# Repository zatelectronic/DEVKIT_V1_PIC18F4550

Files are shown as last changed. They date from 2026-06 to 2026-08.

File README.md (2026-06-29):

<div align="center">

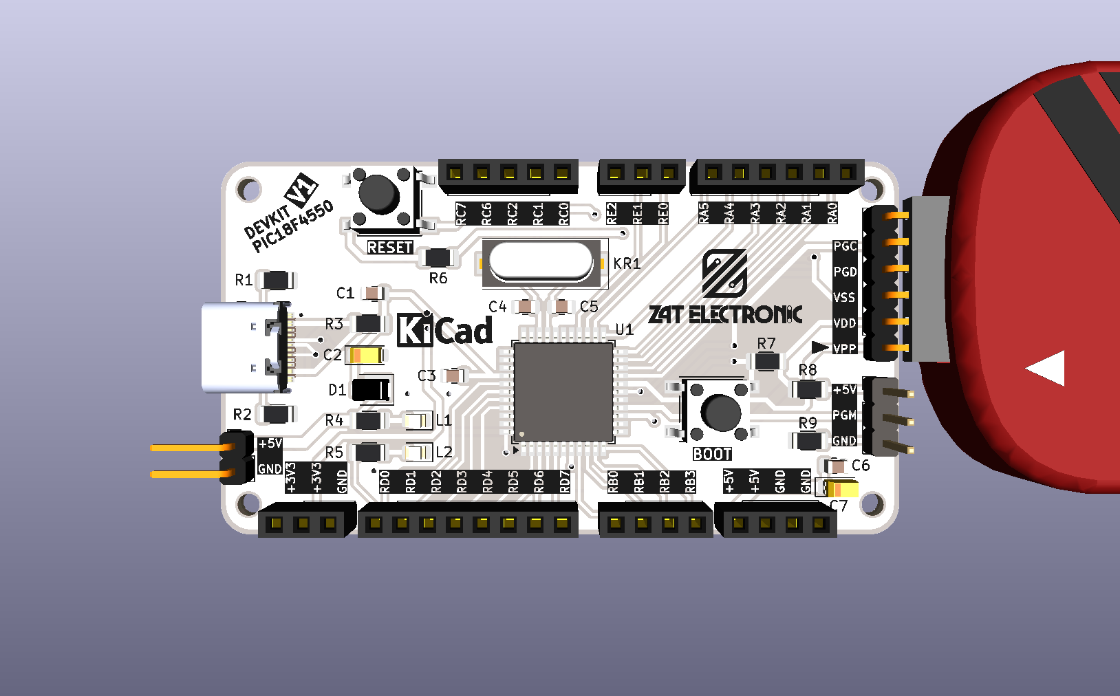
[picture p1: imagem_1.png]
DEVKIT V1 PIC18F4550 — Vista Superior


# DEVKIT V1 PIC18F4550

**Kit de desenvolvimento profissional para o microcontrolador PIC18F4550 com USB nativo, programação via conector ICSP compatível com programador externo, reguladores 5V e 3,3V, oscilador SMD, botões RESET e BOOT, 2 LEDs de status e exposição completa de todos os ports GPIO**










</div>

---

## 📋 Índice

- [DEVKIT V1 PIC18F4550](#devkit-v1-pic18f4550)
  - [📋 Índice](#-índice)
  - [Visão Geral](#visão-geral)
  - [Renders 3D](#renders-3d)
  - [Arquitetura do Projeto](#arquitetura-do-projeto)
  - [Funcionalidades](#funcionalidades)
  - [Especificações Técnicas](#especificações-técnicas)
  - [Arquitetura de Alimentação](#arquitetura-de-alimentação)
  - [Interface USB Nativa](#interface-usb-nativa)
  - [Conector ICSP — Programação](#conector-icsp--programação)
    - [J5 — ICSP Principal (6 pinos angulado)](#j5--icsp-principal-6-pinos-angulado)
    - [J6 — Conector Auxiliar (3 pinos)](#j6--conector-auxiliar-3-pinos)
  - [Mapa Completo de Conectores e GPIO](#mapa-completo-de-conectores-e-gpio)
    - [J1 — Alimentação Externa (2 pinos)](#j1--alimentação-externa-2-pinos)
    - [J2 — Port RA (5 pinos)](#j2--port-ra-5-pinos)
    - [J3 — Port RC Superior (3 pinos)](#j3--port-rc-superior-3-pinos)
    - [J4 — Port RC Inferior (6 pinos)](#j4--port-rc-inferior-6-pinos)
    - [J7 — Port RE (4 pinos)](#j7--port-re-4-pinos)
    - [J8 — Port RB (4 pinos)](#j8--port-rb-4-pinos)
    - [J9 — Port RD (8 pinos)](#j9--port-rd-8-pinos)
    - [J10 — Alimentações (3 pinos)](#j10--alimentações-3-pinos)
  - [Lista de Materiais](#lista-de-materiais)
    - [Microcontrolador](#microcontrolador)
    - [USB Type-C e Alimentação](#usb-type-c-e-alimentação)
    - [Programador ICSP](#programador-icsp)
    - [Conectores GPIO](#conectores-gpio)
  - [Estrutura do Repositório](#estrutura-do-repositório)
  - [Como Usar](#como-usar)
    - [1. Gravando firmware via ICSP](#1-gravando-firmware-via-icsp)
    - [2. Alimentação](#2-alimentação)
    - [3. Modo Bootloader USB (BOOT)](#3-modo-bootloader-usb-boot)
    - [Exemplo de código — MPLAB XC8](#exemplo-de-código--mplab-xc8)
    - [Ferramentas recomendadas](#ferramentas-recomendadas)
  - [Sobre](#sobre)

---

## Visão Geral

**DEVKIT V1 PIC18F4550** é um kit de desenvolvimento completo para o microcontrolador **PIC18F4550-IPT** (TQFP-44 SMD), projetado pela **ZAT ELECTRONIC** utilizando **KiCad 10** com esquemático hierárquico dividido em quatro sub-folhas: **Microcontrolador**, **USB Type-C**, **Programador ICSP** e **Conexões GPIO**.

O PIC18F4550 é um microcontrolador de 8 bits da família PIC18 com **USB 2.0 Full Speed nativo** (RC4/D− e RC5/D+), memória Flash de 32KB, SRAM de 2KB e EEPROM de 256 bytes. O DEVKIT expõe todos os ports GPIO (RA, RB, RC, RD, RE) em conectores fêmea de 2,54mm, inclui reguladores de tensão **5V** e **3,3V** on-board, oscilador a cristal SMD de **8MHz**, botões **RESET** e **BOOT** tácteis SMD, **2 LEDs SMD** de status e conector **ICSP de 6 pinos** angulado compatível com programador externo.

> 💡 O modelo 3D do programador externo (`Microchip - PICkit3.stp`) está incluído no projeto — as imagens 3D mostram o DEVKIT conectado a um programador externo, evidenciando a integração direta pelo conector ICSP lateral.

---

## Renders 3D

<div align="center">

Vista Superior com programador externo

*Vista superior — PIC18F4550 TQFP-44, USB-C, cristal SMD, botões RESET/BOOT e conectores GPIO*

<br/>

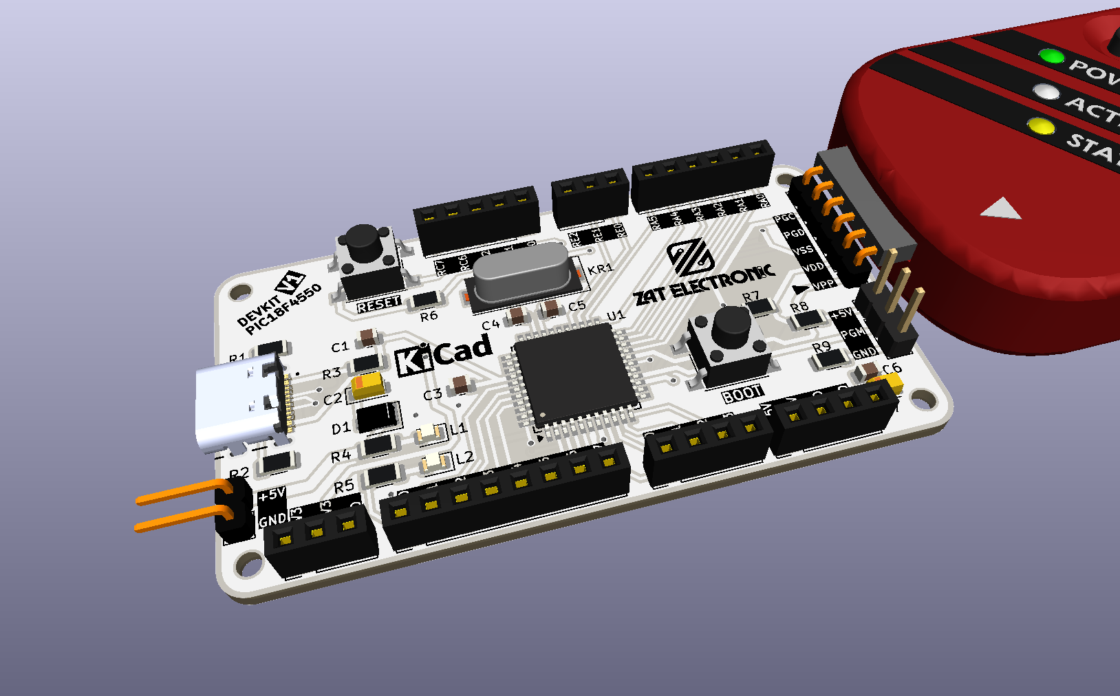
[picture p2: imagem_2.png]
Vista Isométrica com programador externo


*Vista isométrica — DEVKIT conectado ao programador externo pelo conector ICSP de 6 pinos*

<br/>

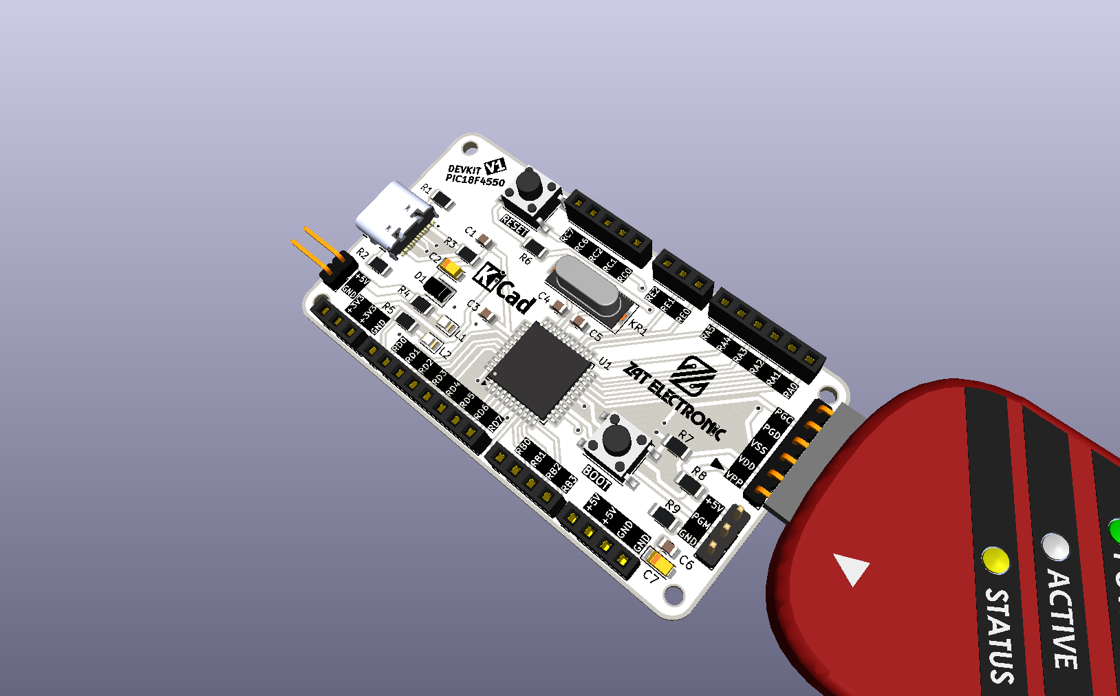
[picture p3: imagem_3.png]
Vista inferior isométrica


*Vista inferior isométrica — exposição completa dos ports RD (8 pinos) e RB (4 pinos) na borda inferior*

<br/>

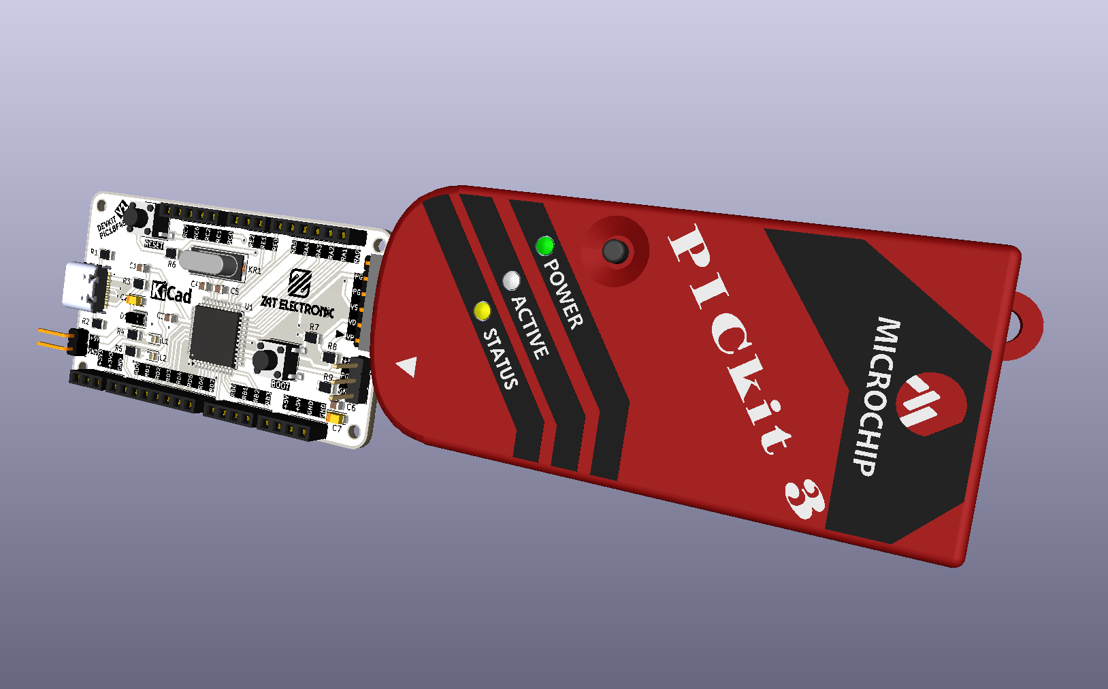
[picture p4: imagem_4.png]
Vista completa com programador


*Visão completa do ecossistema — DEVKIT + programador externo para gravação de firmware*

</div>

---

## Arquitetura do Projeto

O projeto é organizado em **esquemático hierárquico** com 4 sub-folhas independentes:

```
DEVKIT_V1_PIC18F4550.kicad_sch  (folha raiz)
│
├── MICROCONTROLADOR.kicad_sch
│   ├── PIC18F4550-IPT (TQFP-44)
│   ├── Cristal 8MHz HC-49/SD SMD (KR1)
│   ├── Capacitores de cristal 22pF (C3, C4)
│   ├── Capacitor de desacoplamento USB 470nF (C5)
│   ├── Botão RESET táctil SMD (TACTIL_SWITCH1)
│   ├── Botão BOOT táctil SMD (TACTIL_SWITCH2)
│   ├── LEDs SMD 0805 — L1, L2
│   └── Resistores pull-up/proteção — R5, R6, R7
│
├── TYPE-C_USB.kicad_sch
│   ├── Conector USB-C (USB4105GFA SMD)
│   ├── Regulador 3,3V AMS1117-3.3 (U2 — SOT-223)
│   ├── Diodo Schottky SS1P3L (D1 — DO-220AA)
│   ├── Capacitores eletrolíticos 10µF/16V (C2, C8)
│   ├── Capacitores de desacoplamento 100nF (C1, C6)
│   ├── Resistores CC 5,1KΩ (R3, R4 — para USB-C)
│   ├── Resistores 1KΩ e 0Ω (R1, R2)
│   └── LED SMD (L1 — status alimentação)
│
├── PROGRAMADOR.kicad_sch
│   ├── Conector ICSP 6 pinos angulado (J5)
│   ├── Conector auxiliar de programação (J6)
│   └── Resistores pull-up 10KΩ (R8, R9)
│
└── CONEXÕES.kicad_sch
    ├── J1  — Conector alimentação +5V/GND (2 pinos)
    ├── J2  — Port RA (5 pinos: RA0–RA5)
    ├── J3  — Port RC superior (3 pinos: RC0–RC2)
    ├── J4  — Port RC inferior (6 pinos: RC6, RC7)
    ├── J7  — Port RE (4 pinos: RE0–RE2)
    ├── J8  — Port RB (4 pinos: RB0–RB3)
    ├── J9  — Port RD (8 pinos: RD0–RD7)
    └── J10 — Alimentações (3 pinos: +5V / +3,3V / GND)
```

---

## Funcionalidades

- ✅ **PIC18F4550-IPT** (TQFP-44 SMD) — MCU 8 bits, 32KB Flash, 2KB SRAM, 256B EEPROM
- ✅ **USB 2.0 Full Speed nativo** — RC4/D− e RC5/D+ conectados ao conector USB-C
- ✅ **Conector USB-C** (USB4105GFA SMD) — entrada moderna com resistores CC 5,1KΩ
- ✅ **Regulador 3,3V** (AMS1117-3.3 SOT-223) — saída 3,3V para periféricos de baixa tensão
- ✅ **Alimentação 5V** via USB-C ou conector externo J1
- ✅ **Cristal 8MHz SMD** (HC-49/SD) — oscilador externo de alta estabilidade
- ✅ **Botão RESET** (TACTIL_SWITCH1 — SMD 6×6×6mm) — reset do microcontrolador
- ✅ **Botão BOOT** (TACTIL_SWITCH2 — SMD 6×6×6mm) — entrada em modo bootloader USB
- ✅ **2 LEDs SMD 0805** (L1, L2) — indicadores de status programáveis
- ✅ **Conector ICSP J5** — 6 pinos angulado para programador externo (PGC, PGD, MCLR, VDD, VSS, VPP)
- ✅ **Conector auxiliar J6** — 3 pinos (+5V / PGM / GND) para programação low-voltage
- ✅ **Diodo Schottky SS1P3L** (DO-220AA) — proteção na linha VBUS
- ✅ **Todos os ports GPIO expostos** — RA, RB, RC, RD, RE em conectores fêmea 2,54mm
- ✅ **Capacitores de desacoplamento** distribuídos — C3, C4, C5, C6 (0805 SMD)
- ✅ **Capacitores eletrolíticos** C2, C7, C8 (EIA-3216 SMD) — filtragem de alimentação
- ✅ **4 furos de fixação** — montagem em painéis e caixas
- ✅ **Esquemático hierárquico** em 4 sub-folhas — organização profissional do projeto

---

## Especificações Técnicas

| Parâmetro | Valor |
|---|---|
| **Microcontrolador** | PIC18F4550-IPT |
| **Encapsulamento MCU** | TQFP-44 (10×10mm, passo 0,8mm) |
| **Arquitetura** | 8 bits — PIC18 |
| **Memória Flash** | 32 KB |
| **SRAM** | 2 KB |
| **EEPROM** | 256 bytes |
| **USB** | Full Speed 2.0 nativo (12 Mbps) |
| **Clock** | 8 MHz (cristal externo HC-49/SD SMD) |
| **Tensão de operação** | 2,0V – 5,5V |
| **Tensão da placa** | 5V (USB-C ou J1) |
| **Regulador 3,3V** | AMS1117-3.3 (SOT-223) |
| **Conector USB** | USB-C — USB4105GFA SMD |
| **Conector ICSP** | 6 pinos angulado (PGC/PGD/MCLR/VDD/VSS/VPP) |
| **GPIO exposto** | RA (5), RB (4), RC (7), RD (8), RE (3) = 27 pinos |
| **Botões** | RESET + BOOT (SMD táctil 6×6×6mm) |
| **LEDs** | 2x SMD 0805 |
| **Resistores** | SMD 1206 |
| **Capacitores** | SMD 0805 + EIA-3216 |
| **Ferramenta de Projeto** | KiCad 10 — esquemático hierárquico |
| **Tipo de montagem** | SMD |

---

## Arquitetura de Alimentação

```
USB-C (VBUS 5V)
      │
  [SS1P3L D1]  ← Proteção Schottky
      │
     5V ──────────────────────────────────► J1 (+5V)
      │                                     J10 (+5V)
      │                                     VDD do PIC18F4550
      │
  [AMS1117-3.3 U2]
      │
    3,3V ────────────────────────────────► J10 (+3,3V)
                                           Periféricos 3,3V

Alimentação alternativa:
J1 (+5V / GND) ──► entrada direta de fonte externa 5V
```

---

## Interface USB Nativa

O PIC18F4550 possui **USB 2.0 Full Speed integrado** no próprio chip, sem necessidade de conversor externo:

```
USB-C (USB4105GFA)
    │
    ├── D− (CC1/CC2 com 5,1KΩ) ──► RC4/D− do PIC18F4550
    └── D+ (CC1/CC2 com 5,1KΩ) ──► RC5/D+ do PIC18F4550

R3, R4 (5,1KΩ) — resistores CC para identificação USB-C
C5 (470nF)     — capacitor de desacoplamento USB do PIC
```

> 💡 Para utilizar o USB, o firmware deve implementar a pilha USB do PIC18F4550 via bibliotecas como **Microchip USB Framework** ou **USB CDC** para comunicação serial virtual.

---

## Conector ICSP — Programação

O DEVKIT possui conector **ICSP de 6 pinos angulado (J5)** compatível com programador externo e conectores adicionais:

### J5 — ICSP Principal (6 pinos angulado)

| Pino | Sinal | Descrição |
|---|---|---|
| 1 | PGC | Clock de programação (ICSP Clock) |
| 2 | PGD | Dado de programação (ICSP Data) |
| 3 | VSS | GND |
| 4 | VDD | +5V |
| 5 | VPP | Tensão de programação / MCLR |
| 6 | — | (não conectado) |

### J6 — Conector Auxiliar (3 pinos)

| Pino | Sinal | Descrição |
|---|---|---|
| 1 | +5V | Alimentação |
| 2 | PGM | Low-Voltage Programming |
| 3 | GND | Terra |

> 🔴 Para programar com **programador externo** (ex: PICkit 3/4, ICD): conecte o cabo ICSP no conector J5. O modelo 3D do programador está incluído no projeto para visualização do encaixe.

---

## Mapa Completo de Conectores e GPIO

### J1 — Alimentação Externa (2 pinos)

| Pino | Sinal |
|---|---|
| 1 | +5V |
| 2 | GND |

### J2 — Port RA (5 pinos)

| Pino | GPIO | Função alternativa |
|---|---|---|
| 1 | RA0 | AN0 / ADC |
| 2 | RA1 | AN1 / ADC |
| 3 | RA2 | AN2 / VREF− |
| 4 | RA3 | AN3 / VREF+ |
| 5 | RA4 | T0CKI / C1OUT |
| 6 | RA5 | AN4 / SS / HLVDIN |

### J3 — Port RC Superior (3 pinos)

| Pino | GPIO | Função alternativa |
|---|---|---|
| 1 | RC0 | T1OSO / T1CKI |
| 2 | RC1 | T1OSI / CCP2 |
| 3 | RC2 | CCP1 |

### J4 — Port RC Inferior (6 pinos)

| Pino | GPIO | Função alternativa |
|---|---|---|
| 1 | RC6 | TX / CK (USART) |
| 2 | RC7 | RX / DT (USART) |

### J7 — Port RE (4 pinos)

| Pino | GPIO | Função alternativa |
|---|---|---|
| 1 | RE0 | AN5 / RD |
| 2 | RE1 | AN6 / WR |
| 3 | RE2 | AN7 / CS |

### J8 — Port RB (4 pinos)

| Pino | GPIO | Função alternativa |
|---|---|---|
| 1 | RB0 | INT0 / FLT0 / AN12 |
| 2 | RB1 | INT1 / AN10 |
| 3 | RB2 | INT2 / AN8 |
| 4 | RB3 | AN9 / CCP2 |

### J9 — Port RD (8 pinos)

| Pino | GPIO | Função alternativa |
|---|---|---|
| 1 | RD0 | PSP0 |
| 2 | RD1 | PSP1 |
| 3 | RD2 | PSP2 |
| 4 | RD3 | PSP3 |
| 5 | RD4 | PSP4 |
| 6 | RD5 | PSP5 |
| 7 | RD6 | PSP6 |
| 8 | RD7 | PSP7 |

### J10 — Alimentações (3 pinos)

| Pino | Sinal |
|---|---|
| 1 | +5V |
| 2 | +3,3V |
| 3 | GND |

---

## Lista de Materiais

### Microcontrolador

| Ref | Componente | Valor | Encapsulamento |
|-----|---|---|---|
| U1 | Microcontrolador | PIC18F4550-IPT | TQFP-44 SMD |
| KR1 | Cristal | 8MHz | HC-49/SD SMD |
| C3, C4 | Capacitor cristal | 22pF | 0805 SMD |
| C5 | Capacitor USB | 470nF / 50V | 0805 SMD |
| TACTIL_SWITCH1 | Botão RESET | 6×6×6mm | SMD táctil |
| TACTIL_SWITCH2 | Botão BOOT | 6×6×6mm | SMD táctil |
| L1, L2 | LED status | SMD 0805 | 0805 SMD |
| R5 | Resistor LED | 1KΩ | 1206 SMD |
| R6 | Resistor pull-up MCLR | 10KΩ | 1206 SMD |
| R7 | Resistor pull-up BOOT | 10KΩ | 1206 SMD |

### USB Type-C e Alimentação

| Ref | Componente | Valor | Encapsulamento |
|-----|---|---|---|
| USBC1 | Conector USB-C | USB4105GFA | SMD |
| U2 | Regulador 3,3V | AMS1117-3.3 | SOT-223 SMD |
| D1 | Diodo Schottky | SS1P3L | DO-220AA SMD |
| C1, C6 | Capacitor desacoplamento | 100nF / 50V | 0805 SMD |
| C2, C8 | Capacitor eletrolítico | 10µF / 16V | EIA-3216 SMD |
| C7 | Capacitor eletrolítico | 10µF / 16V | EIA-3216 SMD |
| R1 | Resistor | 0Ω (jumper) | 1206 SMD |
| R2 | Resistor | 1KΩ | 1206 SMD |
| R3, R4 | Resistores CC USB-C | 5,1KΩ | 1206 SMD |

### Programador ICSP

| Ref | Componente | Valor | Encapsulamento |
|-----|---|---|---|
| J5 | Conector ICSP | 6 pinos angulado | Header 2,54mm |
| J6 | Conector auxiliar | 3 pinos | Header 2,54mm |
| R8 | Resistor pull-up PGC | 10KΩ | 1206 SMD |
| R9 | Resistor pull-up PGD | 10KΩ | 1206 SMD |

### Conectores GPIO

| Ref | Descrição | Pinos |
|-----|---|---|
| J1 | Alimentação externa | 2 pinos (2,54mm angulado) |
| J2 | Port RA | 5 pinos fêmea 2,54mm |
| J3 | Port RC superior | 3 pinos fêmea 2,54mm |
| J4 | Port RC inferior | 6 pinos fêmea 2,54mm |
| J7 | Port RE | 4 pinos fêmea 2,54mm |
| J8 | Port RB | 4 pinos fêmea 2,54mm |
| J9 | Port RD | 8 pinos fêmea 2,54mm |
| J10 | Alimentações | 3 pinos fêmea 2,54mm |

---

## Estrutura do Repositório

```
DEVKIT_V1_PIC18F4550/
├── DEVKIT_V1_PIC18F4550.kicad_pro    # Arquivo de projeto KiCad
├── DEVKIT_V1_PIC18F4550.kicad_sch    # Esquemático raiz (hierárquico)
├── DEVKIT_V1_PIC18F4550.kicad_pcb    # Layout da PCB (KiCad 10)
├── DEVKIT_V1_PIC18F4550.kicad_prl    # Configurações locais
├── MICROCONTROLADOR.kicad_sch        # Sub-folha: MCU + cristal + botões + LEDs
├── TYPE-C_USB.kicad_sch              # Sub-folha: USB-C + reguladores + proteção
├── PROGRAMADOR.kicad_sch             # Sub-folha: ICSP + conector programador
├── CONEXÕES.kicad_sch                # Sub-folha: todos os conectores GPIO
├── PIC18F4550_DATASHEET.pdf          # Datasheet oficial do PIC18F4550
├── packages3D/                       # Modelos 3D arquivados (STEP / WRL)
│   ├── TQFP-44_10x10mm_P0.8mm.wrl
│   ├── USB4105GFA.STEP
│   ├── SOT-223.wrl
│   ├── Crystal_SMD_HC49-SD.wrl
│   ├── Tactal Switch - SMD 6x6x6.stp
│   ├── LED_0805_2012Metric.wrl
│   ├── D_SMP_DO-220AA.wrl
│   ├── Microchip - PICkit3.stp
│   ├── PinHeader_6X1_right.stp
│   ├── PinHeader_2X1_right.stp
│   └── *-Pin Header - Female - 2.54mm.step
├── fp-info-cache                     # Cache de footprints
├── imagem_1.png                      # Render 3D superior
├── imagem_2.png                      # Render 3D isométrico com programador
├── imagem_3.png                      # Render 3D traseiro
├── imagem_4.png                      # Render 3D completo com programador
└── README.md
```

---

## Como Usar

### 1. Gravando firmware via ICSP

1. Conecte o programador externo ao conector **J5** (6 pinos angulado)
2. Abra o **MPLAB X IDE** e configure o projeto para **PIC18F4550**
3. Selecione o programador (ex: PICkit 3/4) e clique em **Make and Program Device**
4. O LED de status confirmará o sucesso da gravação

### 2. Alimentação

```
Opção A — Via USB-C:
  Conecte cabo USB-C → alimentação automática 5V via VBUS

Opção B — Via conector externo J1:
  Aplique +5V no pino 1 e GND no pino 2 do conector J1
```

### 3. Modo Bootloader USB (BOOT)

```
1. Mantenha o botão BOOT pressionado
2. Pressione e solte o botão RESET
3. Solte o botão BOOT
4. O PIC18F4550 entrará em modo bootloader USB
5. Grave o firmware via software de bootloader (ex: HIDBootloader)
```

### Exemplo de código — MPLAB XC8

```c
#include <xc.h>

// Configurações básicas do PIC18F4550
#pragma config FOSC = HS        // Oscilador externo HS
#pragma config WDT = OFF        // Watchdog desabilitado
#pragma config MCLRE = ON       // MCLR ativo
#pragma config LVP = OFF        // Low-voltage programming off
#pragma config PBADEN = OFF     // PORTB digital

#define _XTAL_FREQ 8000000

void main(void) {
    TRISDbits.TRISD0 = 0;   // RD0 como saída (J9 pino 1)
    TRISDbits.TRISD1 = 0;   // RD1 como saída (J9 pino 2)

    while(1) {
        LATDbits.LATD0 = 1;  // RD0 HIGH
        __delay_ms(500);
        LATDbits.LATD0 = 0;  // RD0 LOW
        __delay_ms(500);
    }
}
```

### Ferramentas recomendadas

| Ferramenta | Finalidade |
|---|---|
| MPLAB X IDE | IDE oficial para desenvolvimento PIC |
| XC8 Compiler | Compilador C para PIC de 8 bits |
| Programador externo | Gravação via ICSP (J5) |
| MPLAB Code Configurator | Geração automática de configuração de periféricos |
| Microchip USB Framework | Implementação da pilha USB do PIC18F4550 |

---

## Sobre

<div align="center">

Projetado por **ZAT ELECTRONIC**

*DEVKIT V1 PIC18F4550 — Made in Brazil 🇧🇷*





</div>

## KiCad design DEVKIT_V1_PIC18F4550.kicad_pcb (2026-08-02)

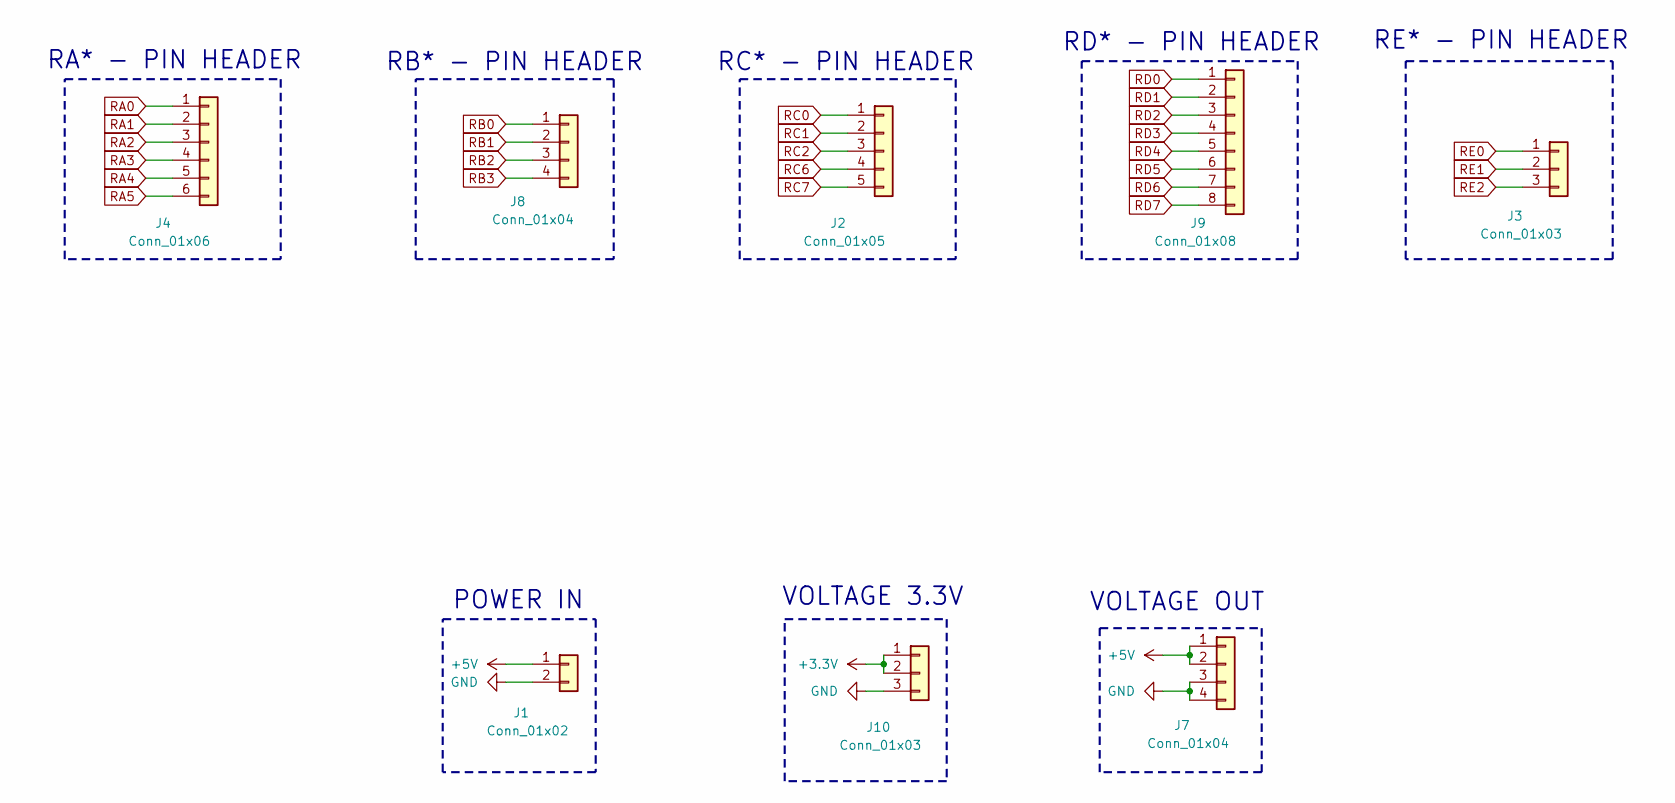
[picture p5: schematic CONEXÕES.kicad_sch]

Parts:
J1: Conn_01x02; PinHeader_1x02_P2.54mm_Vertical
J2: Conn_01x05; PinHeader_1x05_P2.54mm_Vertical
J3, J10: Conn_01x03; PinHeader_1x03_P2.54mm_Vertical
J4: Conn_01x06; PinHeader_1x06_P2.54mm_Vertical
J7, J8: Conn_01x04; PinHeader_1x04_P2.54mm_Vertical
J9: Conn_01x08; PinHeader_1x08_P2.54mm_Vertical

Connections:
+3.3V: J10.1, J10.2; also elsewhere on the board
+5V: J1.1, J7.1, J7.2; also elsewhere on the board
GND: J1.2, J7.3, J7.4, J10.3; also elsewhere on the board
RA0: J4.1; also elsewhere on the board
RA1: J4.2; also elsewhere on the board
RA2: J4.3; also elsewhere on the board
RA3: J4.4; also elsewhere on the board
RA4: J4.5; also elsewhere on the board
RA5: J4.6; also elsewhere on the board
RB0: J8.1; also elsewhere on the board
RB1: J8.2; also elsewhere on the board
RB2: J8.3; also elsewhere on the board
RB3: J8.4; also elsewhere on the board
RC0: J2.1; also elsewhere on the board
RC1: J2.2; also elsewhere on the board
RC2: J2.3; also elsewhere on the board
RC6: J2.4; also elsewhere on the board
RC7: J2.5; also elsewhere on the board
RD0: J9.1; also elsewhere on the board
RD1: J9.2; also elsewhere on the board
RD2: J9.3; also elsewhere on the board
RD3: J9.4; also elsewhere on the board
RD4: J9.5; also elsewhere on the board
RD5: J9.6; also elsewhere on the board
RD6: J9.7; also elsewhere on the board
RD7: J9.8; also elsewhere on the board
RE0: J3.1; also elsewhere on the board
RE1: J3.2; also elsewhere on the board
RE2: J3.3; also elsewhere on the board

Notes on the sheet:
VOLTAGE 3.3V
POWER IN
RC* - PIN HEADER
RB* - PIN HEADER
VOLTAGE OUT
RD* - PIN HEADER
RE* - PIN HEADER
RA* - PIN HEADER

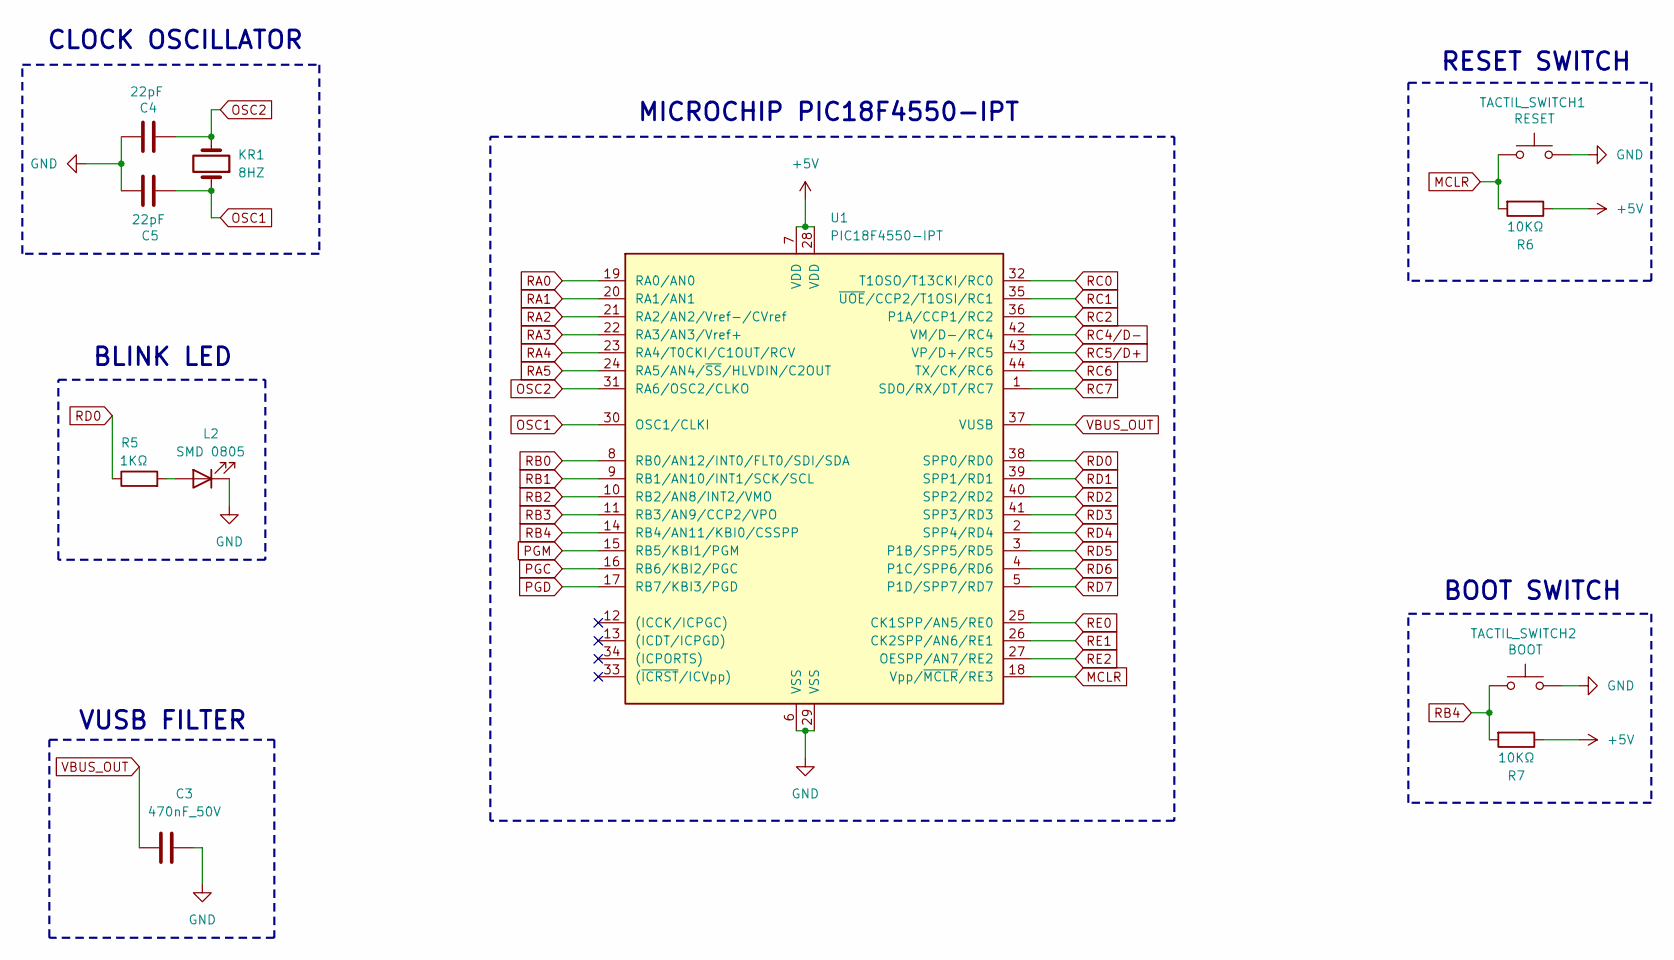
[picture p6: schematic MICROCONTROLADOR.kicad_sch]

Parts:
C3: 470nF_50V; C_0805_2012Metric
C4, C5: 22pF; C_0805_2012Metric
KR1: 8HZ; Crystal_SMD_HC49-SD
L2: SMD 0805; LED_0805_2012Metric
R5: 1KΩ; R_1206_3216Metric
R6, R7: 10KΩ; R_1206_3216Metric
TACTIL_SWITCH1: RESET; SW_Push_1P1T_NO_6x6mm_H9.5mm
TACTIL_SWITCH2: BOOT; SW_Push_1P1T_NO_6x6mm_H9.5mm
U1: PIC18F4550-IPT; TQFP-44_10x10mm_P0.8mm

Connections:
+5V: R6.1, R7.1, U1.7 (VDD), U1.28 (VDD); also elsewhere on the board
GND: C3.1, C4.2, C5.2, L2.1 (K), TACTIL_SWITCH1.2, TACTIL_SWITCH2.2, U1.6 (VSS), U1.29 (VSS); also elsewhere on the board
MCLR: R6.2, TACTIL_SWITCH1.1, U1.18 (Vpp/~MCLR/RE3); also elsewhere on the board
unnamed: L2.2 (A), R5.2
OSC1: C5.1, KR1.1, U1.30 (OSC1/CLKI)
OSC2: C4.1, KR1.2, U1.31 (RA6/OSC2/CLKO)
PGC: U1.16 (RB6/KBI2/PGC); also elsewhere on the board
PGD: U1.17 (RB7/KBI3/PGD); also elsewhere on the board
PGM: U1.15 (RB5/KBI1/PGM); also elsewhere on the board
RA0: U1.19 (RA0/AN0); also elsewhere on the board
RA1: U1.20 (RA1/AN1); also elsewhere on the board
RA2: U1.21 (RA2/AN2/Vref-/CVref); also elsewhere on the board
RA3: U1.22 (RA3/AN3/Vref+); also elsewhere on the board
RA4: U1.23 (RA4/T0CKI/C1OUT/RCV); also elsewhere on the board
RA5: U1.24 (RA5/AN4/~SS/HLVDIN/C2OUT); also elsewhere on the board
RB0: U1.8 (RB0/AN12/INT0/FLT0/SDI/SDA); also elsewhere on the board
RB1: U1.9 (RB1/AN10/INT1/SCK/SCL); also elsewhere on the board
RB2: U1.10 (RB2/AN8/INT2/VMO); also elsewhere on the board
RB3: U1.11 (RB3/AN9/CCP2/VPO); also elsewhere on the board
RB4: R7.2, TACTIL_SWITCH2.1, U1.14 (RB4/AN11/KBI0/CSSPP)
RC0: U1.32 (T1OSO/T13CKI/RC0); also elsewhere on the board
RC1: U1.35 (~UOE/CCP2/T1OSI/RC1); also elsewhere on the board
RC2: U1.36 (P1A/CCP1/RC2); also elsewhere on the board
RC4/D-: U1.42 (VM/D-/RC4); also elsewhere on the board
RC5/D+: U1.43 (VP/D+/RC5); also elsewhere on the board
RC6: U1.44 (TX/CK/RC6); also elsewhere on the board
RC7: U1.1 (SDO/RX/DT/RC7); also elsewhere on the board
RD0: R5.1, U1.38 (SPP0/RD0); also elsewhere on the board
RD1: U1.39 (SPP1/RD1); also elsewhere on the board
RD2: U1.40 (SPP2/RD2); also elsewhere on the board
RD3: U1.41 (SPP3/RD3); also elsewhere on the board
RD4: U1.2 (SPP4/RD4); also elsewhere on the board
RD5: U1.3 (P1B/SPP5/RD5); also elsewhere on the board
RD6: U1.4 (P1C/SPP6/RD6); also elsewhere on the board
RD7: U1.5 (P1D/SPP7/RD7); also elsewhere on the board
RE0: U1.25 (CK1SPP/AN5/RE0); also elsewhere on the board
RE1: U1.26 (CK2SPP/AN6/RE1); also elsewhere on the board
RE2: U1.27 (OESPP/AN7/RE2); also elsewhere on the board
VBUS_OUT: C3.2, U1.37 (VUSB); also elsewhere on the board

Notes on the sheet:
CLOCK OSCILLATOR
BLINK LED
VUSB FILTER
BOOT SWITCH
MICROCHIP PIC18F4550-IPT
RESET SWITCH

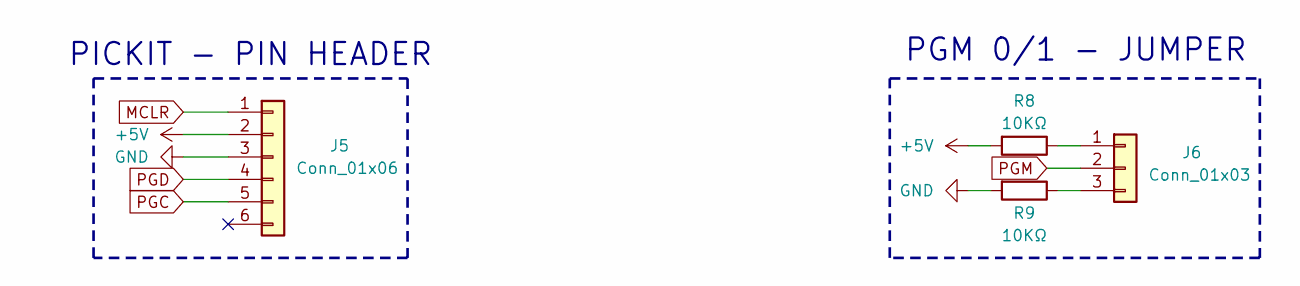
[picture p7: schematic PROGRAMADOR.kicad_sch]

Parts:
J5: Conn_01x06; PinHeader_1x06_P2.54mm_Vertical
J6: Conn_01x03; PinHeader_1x03_P2.54mm_Vertical
R8, R9: 10KΩ; R_1206_3216Metric

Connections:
+5V: J5.2, R8.2; also elsewhere on the board
GND: J5.3, R9.2; also elsewhere on the board
MCLR: J5.1; also elsewhere on the board
unnamed: J6.1, R8.1
unnamed: J6.3, R9.1
PGC: J5.5; also elsewhere on the board
PGD: J5.4; also elsewhere on the board
PGM: J6.2; also elsewhere on the board

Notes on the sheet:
PGM 0/1 - JUMPER
PICKIT - PIN HEADER

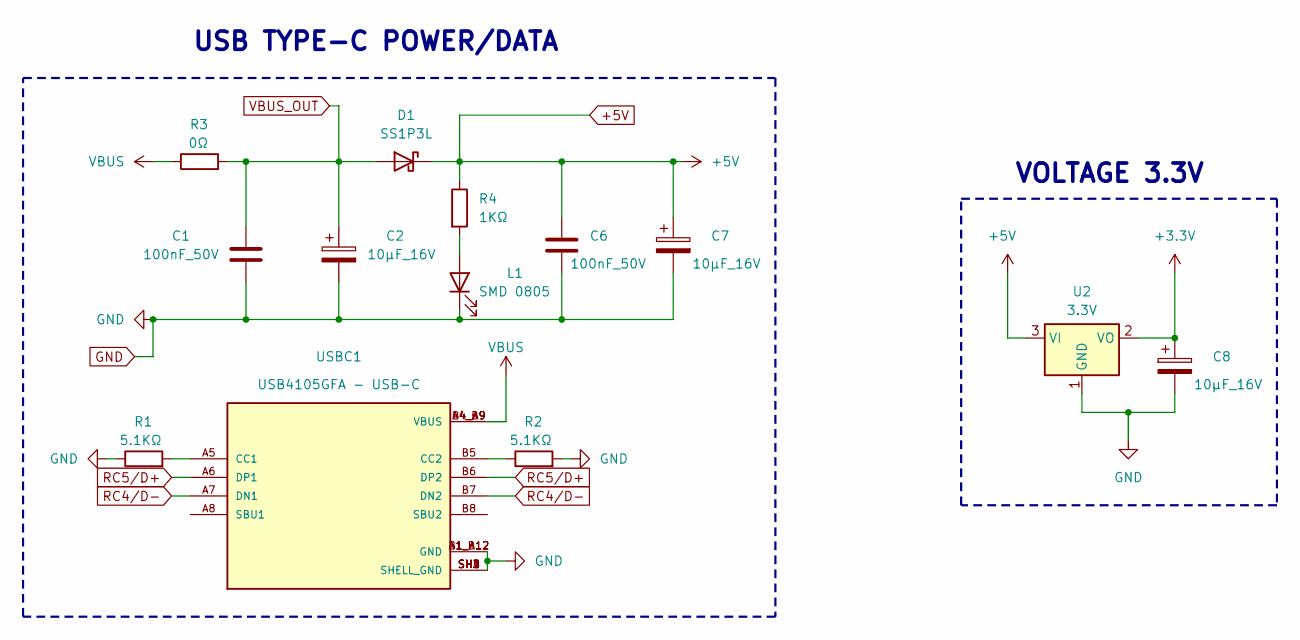
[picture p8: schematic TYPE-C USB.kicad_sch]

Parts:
C1, C6: 100nF_50V; C_0805_2012Metric
C2, C7, C8: 10μF_16V; CP_EIA-3216-18_Kemet-A
D1: SS1P3L; D_SMP_DO-220AA
L1: SMD 0805; LED_0805_2012Metric
R1, R2: 5.1KΩ; R_1206_3216Metric
R3: 0Ω; R_1206_3216Metric
R4: 1KΩ; R_1206_3216Metric
U2: 3.3V; SOT-223-3_TabPin2
USBC1: USB4105GFA - USB-C; USB4105GFA; PARTREV B3

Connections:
+3.3V: C8.1, U2.2 (VO); also elsewhere on the board
+5V: C6.1, C7.1, D1.1 (K), R4.1, U2.3 (VI); also elsewhere on the board
GND: C1.2, C2.2, C6.2, C7.2, C8.2, L1.1 (K), R1.1, R2.2, U2.1 (GND), USBC1.A1_B12 (GND), USBC1.B1_A12 (GND), USBC1.SH1 (SHELL_GND), USBC1.SH2 (SHELL_GND), USBC1.SH3 (SHELL_GND), USBC1.SH4 (SHELL_GND); also elsewhere on the board
unnamed: L1.2 (A), R4.2
unnamed: R1.2, USBC1.A5 (CC1)
unnamed: R2.1, USBC1.B5 (CC2)
RC4/D-: USBC1.A7 (DN1), USBC1.B7 (DN2); also elsewhere on the board
RC5/D+: USBC1.A6 (DP1), USBC1.B6 (DP2); also elsewhere on the board
VBUS: R3.1, USBC1.A4_B9 (VBUS), USBC1.B4_A9 (VBUS)
VBUS_OUT: C1.1, C2.1, D1.2 (A), R3.2; also elsewhere on the board

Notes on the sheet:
VOLTAGE 3.3V
USB TYPE-C POWER/DATA

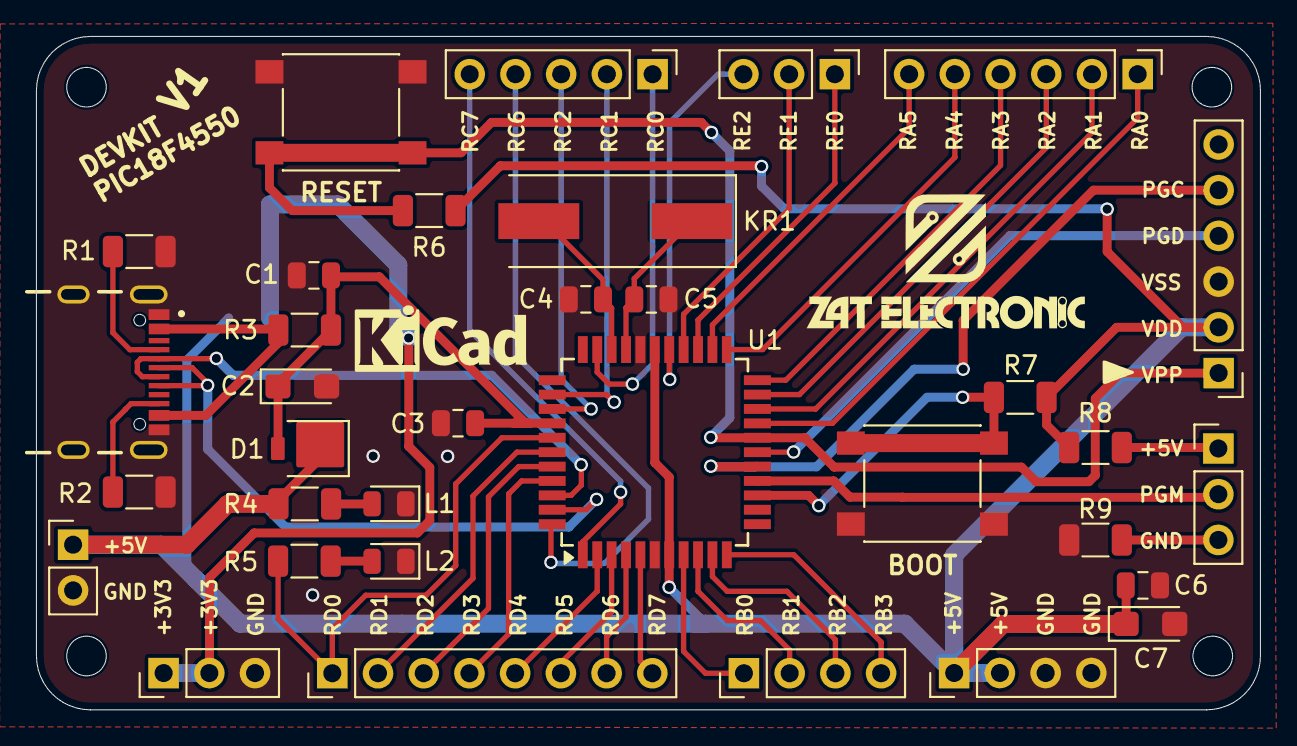
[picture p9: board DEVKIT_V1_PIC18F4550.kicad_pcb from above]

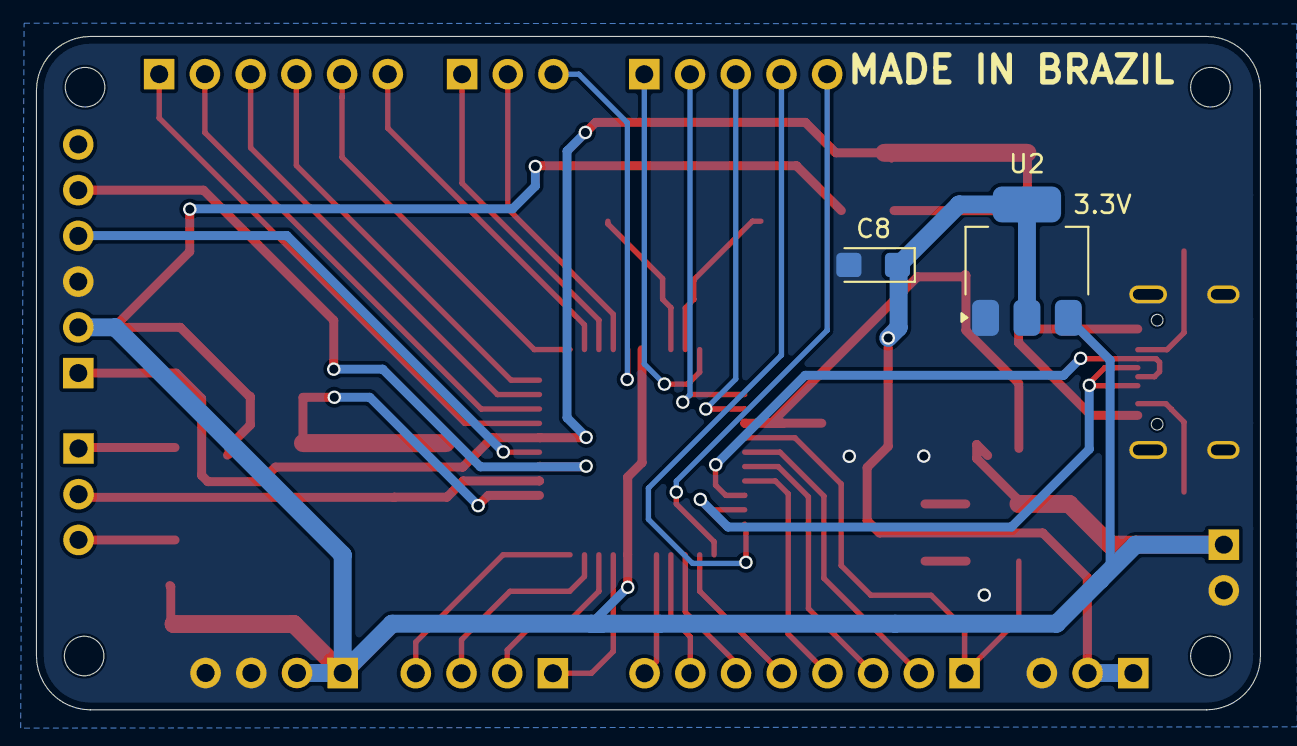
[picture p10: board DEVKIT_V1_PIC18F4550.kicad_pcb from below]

Board: 4 copper layers, 68.0 x 37.4 mm, 36 parts (2 on the bottom side), 46 nets.

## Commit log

2026-07-28 COMMIT - 28072026
    [DEVKIT_V1_PIC18F4550.kicad_pcb]
2026-07-29 COMMIT 2 - 28/07/2026
    [CONEXÕES.kicad_sch, DEVKIT_V1_PIC18F4550.kicad_sch, MICROCONTROLADOR.kicad_sch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]
2026-07-29 COMMIT 3 - 28/07/2026
    [CONEXÕES.kicad_sch, DEVKIT_V1_PIC18F4550.kicad_sch, MICROCONTROLADOR.kicad_sch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]
2026-08-02 COMMIT - 02/08/2026
    [DEVKIT_V1_PIC18F4550.kicad_pcb]
